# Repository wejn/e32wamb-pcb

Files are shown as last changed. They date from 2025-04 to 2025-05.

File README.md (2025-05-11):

# Hue White Ambiance replacement using ESP32

**Note: This is work in progress, not guaranteed to be usable.**

This will be a pcb for my Hue White Ambiance replacement driver
suitable for my "Beng Ceiling Light" from Philips.

For background info see
[Reversing Philips Hue light driver](https://wejn.org/2024/12/reversing-philips-hue-light-driver/),
or directly the [Final stretch for e32wamb: PCB, cables, antenna
holder](https://wejn.org/2025/05/finishing-stretch-for-e32wamb-pcb-cables-antenna-holder/)
post that discusses the PCB in particular.

## Pretty pictures

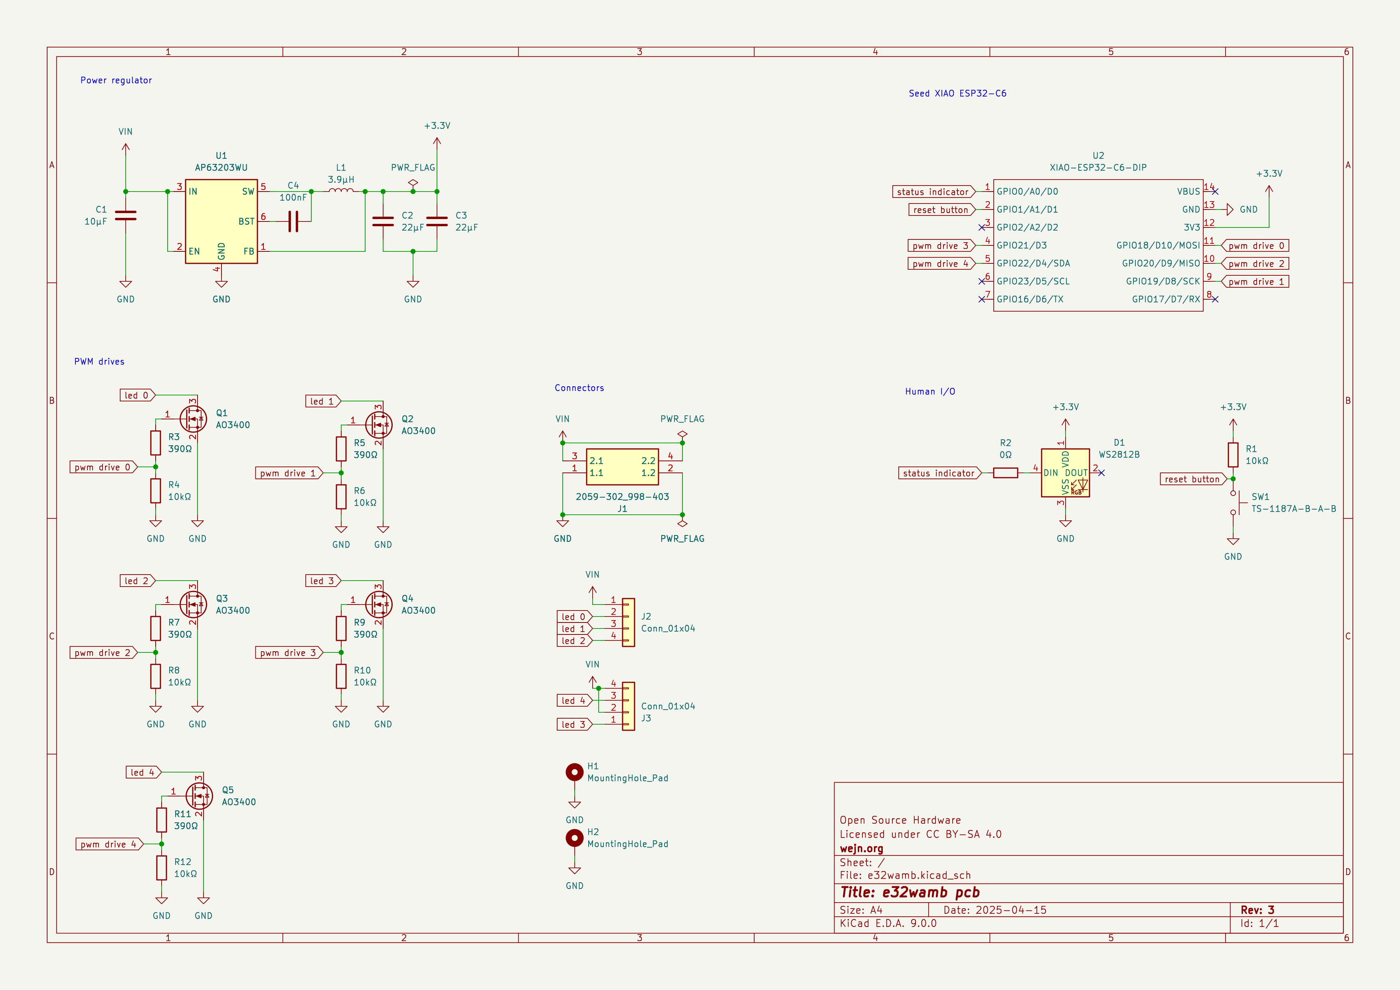
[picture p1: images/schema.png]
schema


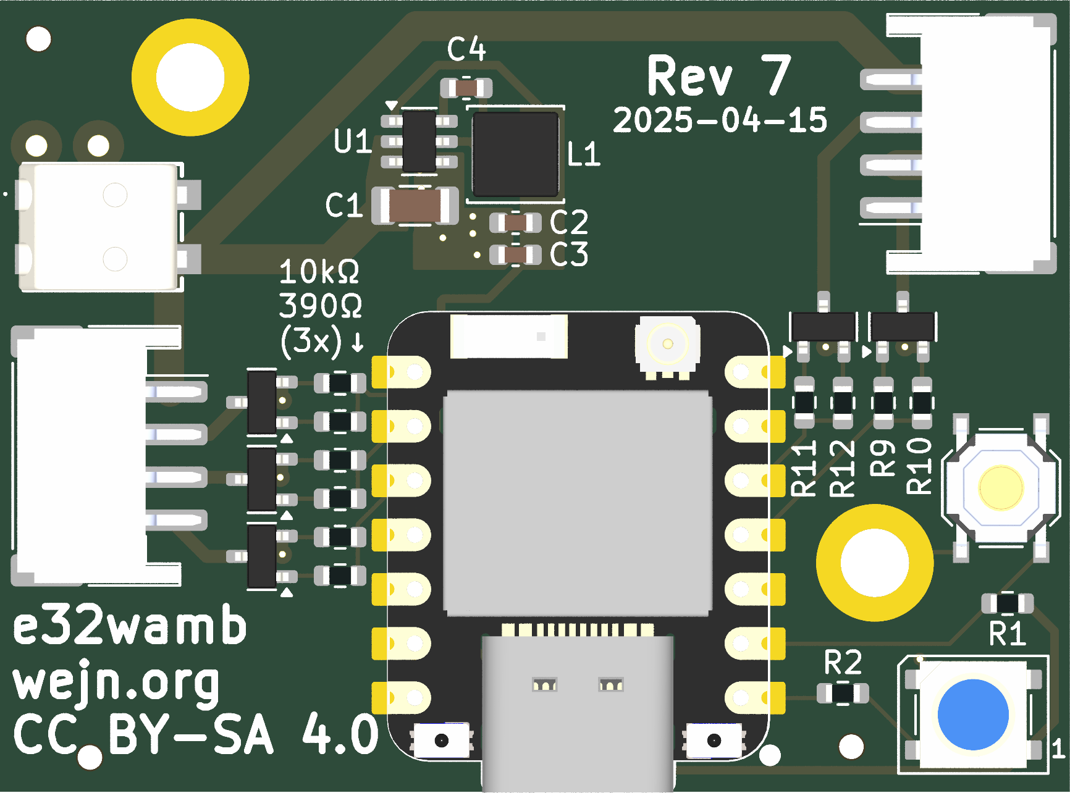
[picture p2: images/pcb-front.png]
pcb front


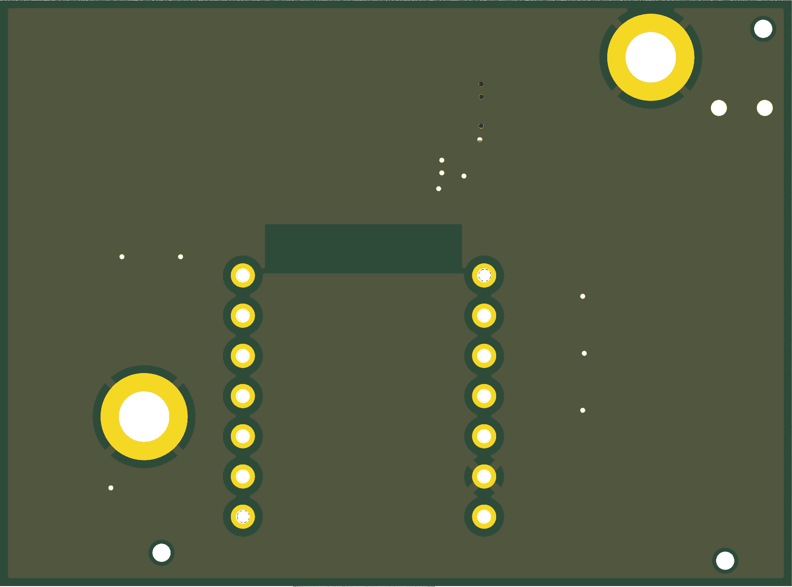
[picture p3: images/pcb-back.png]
pcb back


## License

See the `LICENSE.md` file (tl;dr: CC BY-SA 4.0 for anything by me)

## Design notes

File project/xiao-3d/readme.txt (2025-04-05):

https://grabcad.com/library/seeed-studio-xiao-esp32-c6-1

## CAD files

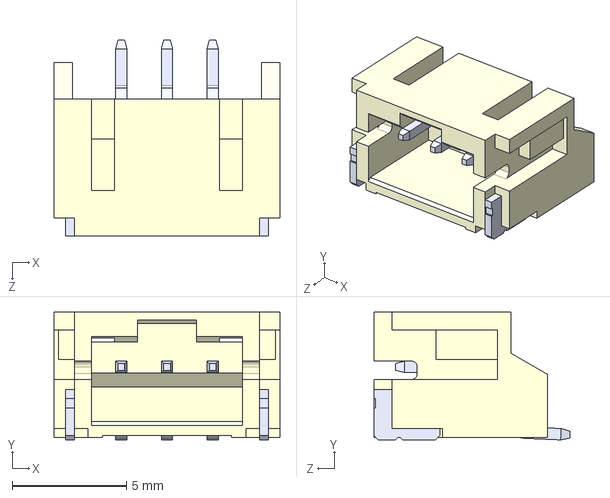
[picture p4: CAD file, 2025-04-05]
project/jst-3d/S3B-PH-SM4-TB--3DModel-STEP-269445.STEP
9.90 x 5.60 x 8.60 mm

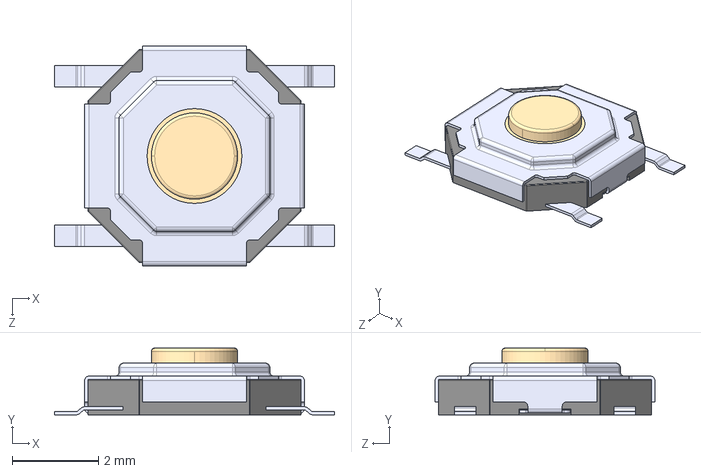
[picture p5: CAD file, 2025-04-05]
project/ts1187a-3d/TS-1187A-B-A-B--3DModel-STEP-56544.STEP
6.50 x 1.55 x 5.10 mm

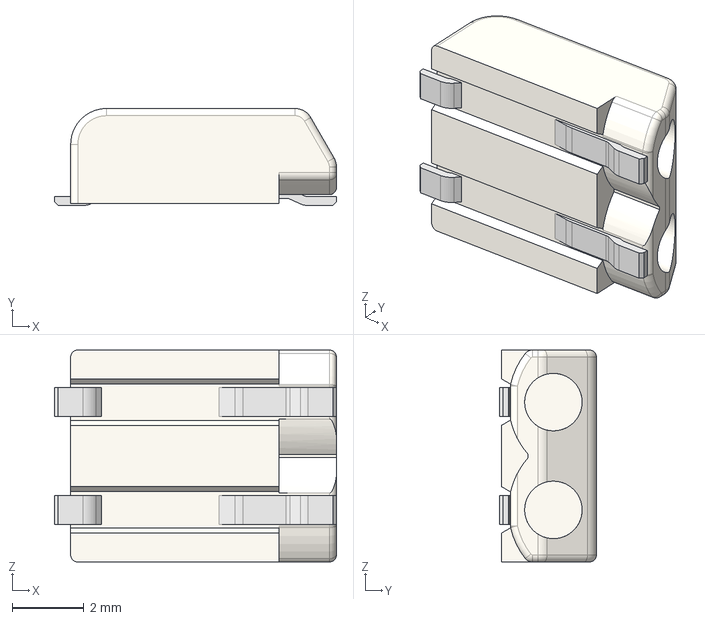
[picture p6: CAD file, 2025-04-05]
project/wago-connector/2059-302_998-403.stp
7.85 x 2.70 x 5.90 mm

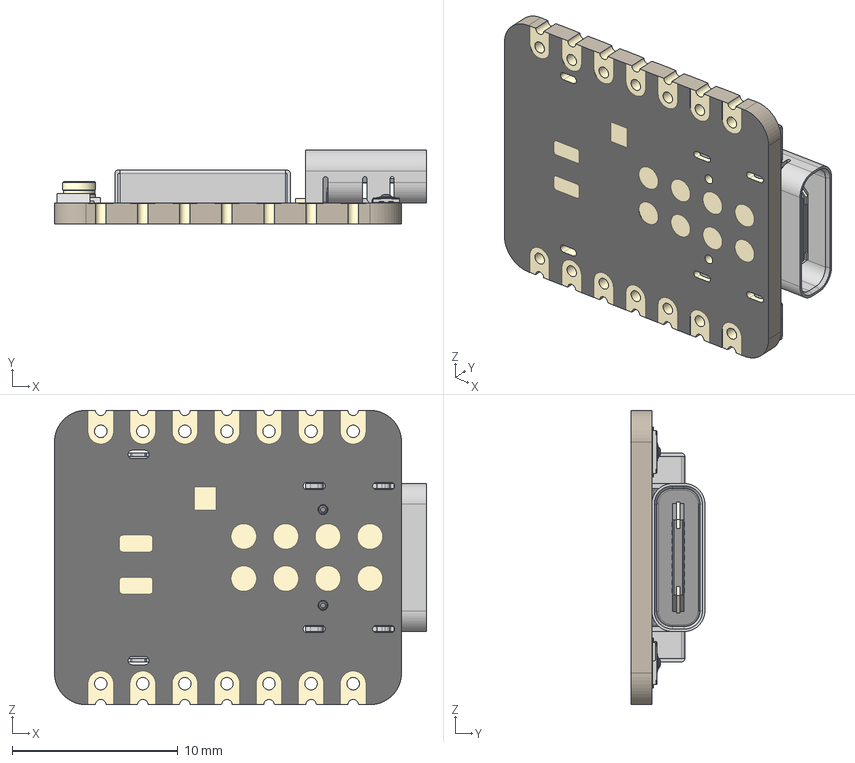
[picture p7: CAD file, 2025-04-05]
project/xiao-3d/Seeed Studio XIAO ESP32-C6.step
22.5 x 4.46 x 17.8 mm
BOSS-EXTRUDE14_8_
BOSS-EXTRUDE7_4_
BOSS-EXTRUDE7_3_
BOSS-EXTRUDE14_4_
BOSS-EXTRUDE14_2_
BOSS-EXTRUDE14_11_
BOSS-EXTRUDE7_7_
BOSS-EXTRUDE14_9_
BOSS-EXTRUDE14_3_
BOSS-EXTRUDE14_7_
MIRROR2
BOSS-EXTRUDE14_5_
BOSS-EXTRUDE14_12_
BOSS-EXTRUDE7_8_
BOSS-EXTRUDE7_1_
BOSS-EXTRUDE14_10_
BOSS-EXTRUDE7_9_
BOSS-EXTRUDE14_6_
BOSS-EXTRUDE14_1_
BOSS-EXTRUDE7_6_
BOSS-EXTRUDE7_2_
CUT-EXTRUDE5
BOSS-EXTRUDE7_5_
U.FL Connector v1
Shield
SKTAAAE010 x 2
KH5220-A36 (Ceramic Antenna) v2

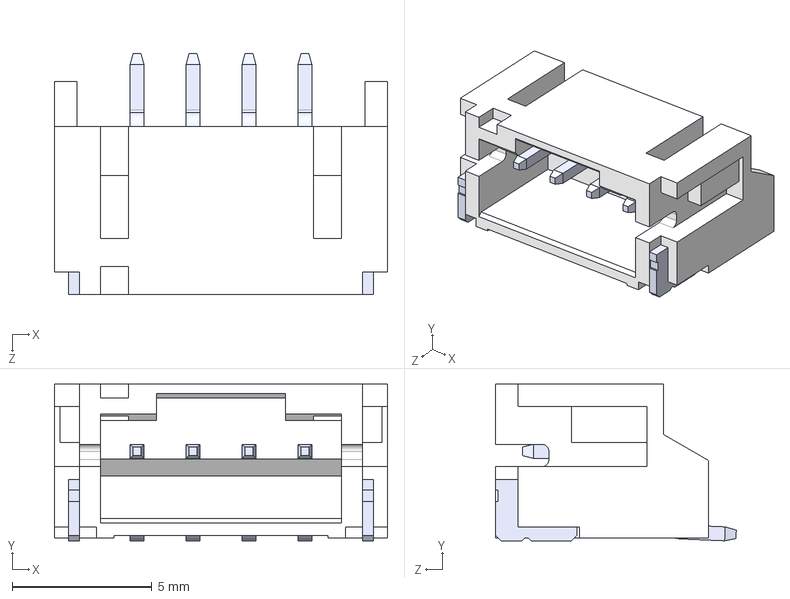
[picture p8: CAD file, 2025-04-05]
project/jst-3d/S4B-PH-SM4-TB--3DModel-STEP-56544.STEP
11.9 x 5.60 x 8.60 mm

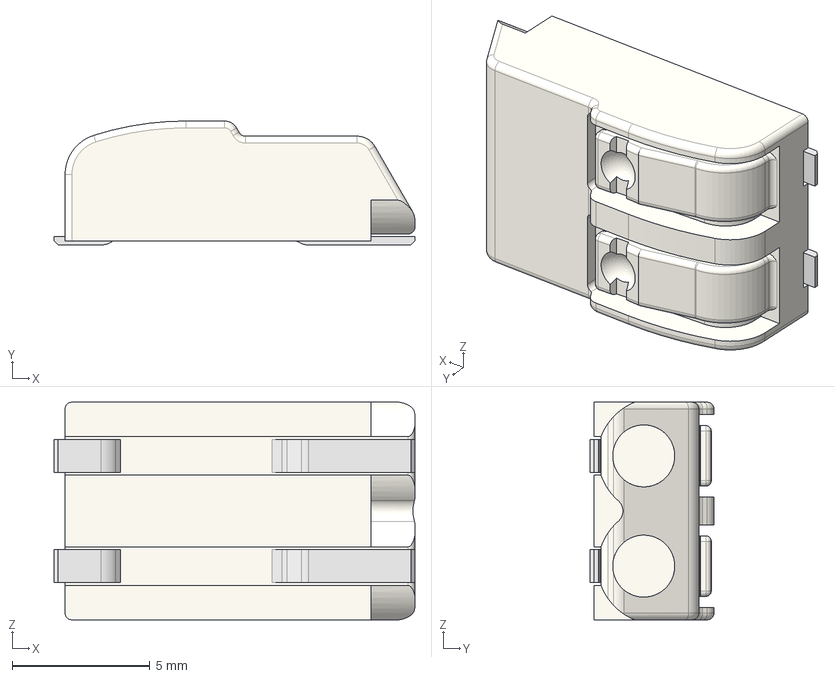
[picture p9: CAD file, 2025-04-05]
project/wago-connector/2060-452_998-404.stp
13.1 x 4.50 x 7.90 mm

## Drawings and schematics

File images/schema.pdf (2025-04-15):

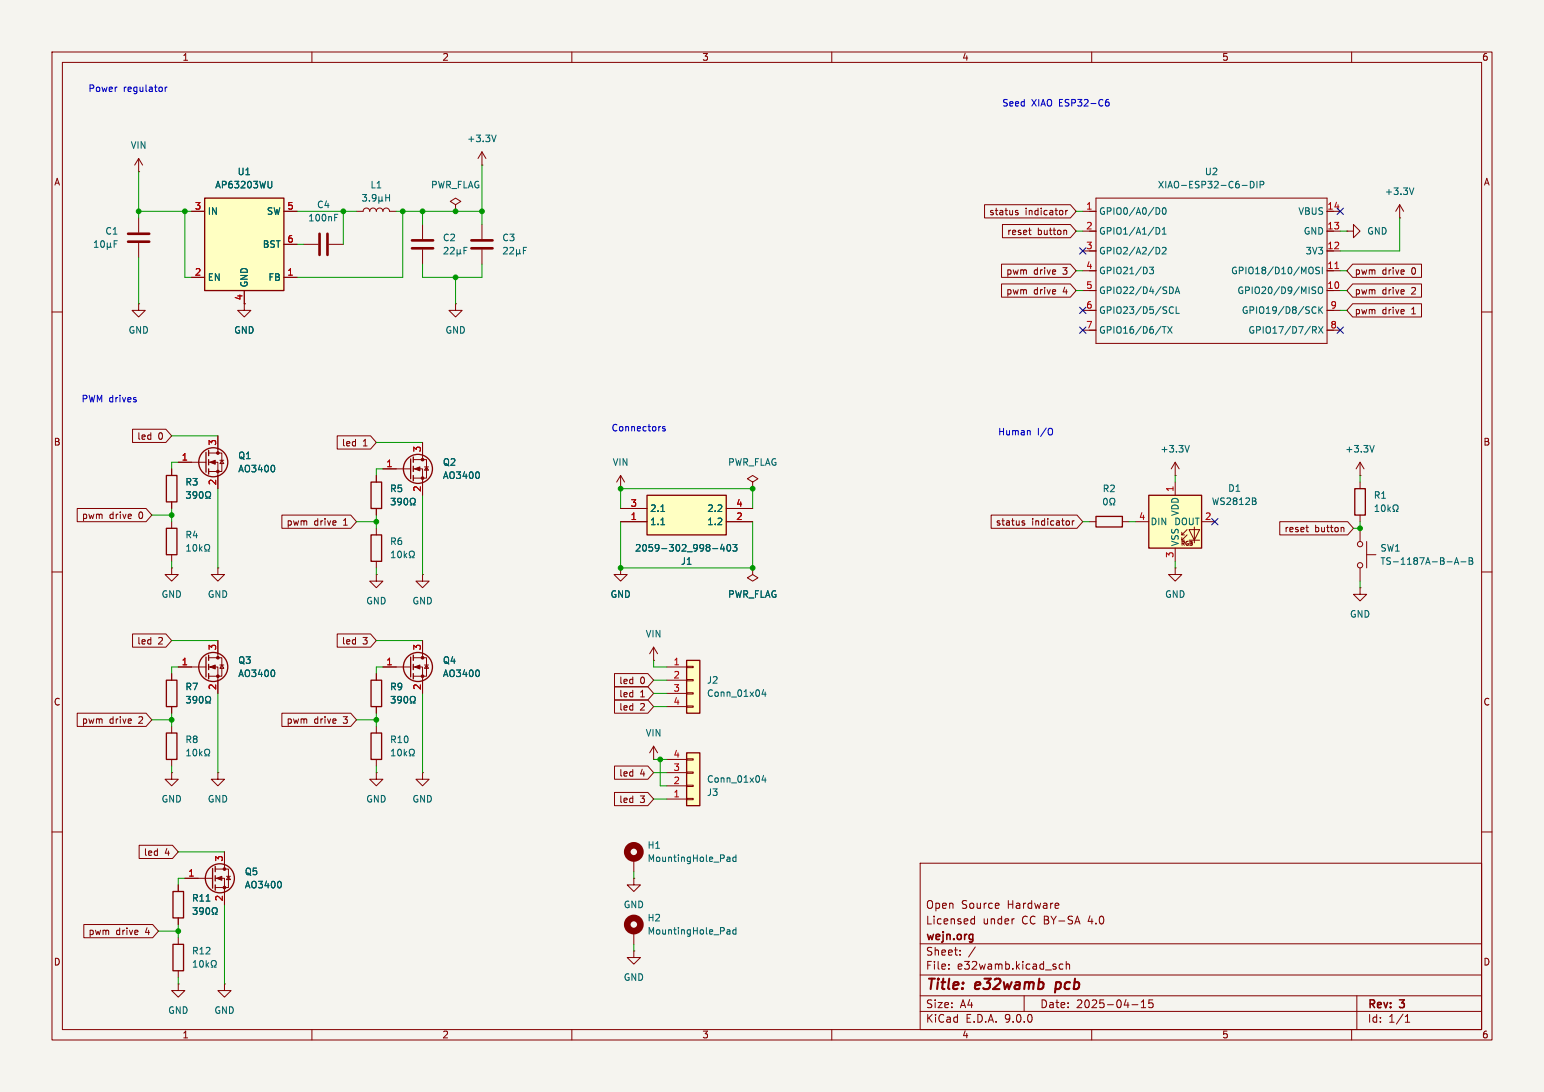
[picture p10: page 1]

4 SW 5 BST 6 FB 1 U1 AP63203WU GND GND

4 SW 5 BST 6 FB 1 GND Q1 AO3400

pwm drive 0
status indicator pwm drive 4

File: e32wamb.kicad_sch Sheet: / wejn.org

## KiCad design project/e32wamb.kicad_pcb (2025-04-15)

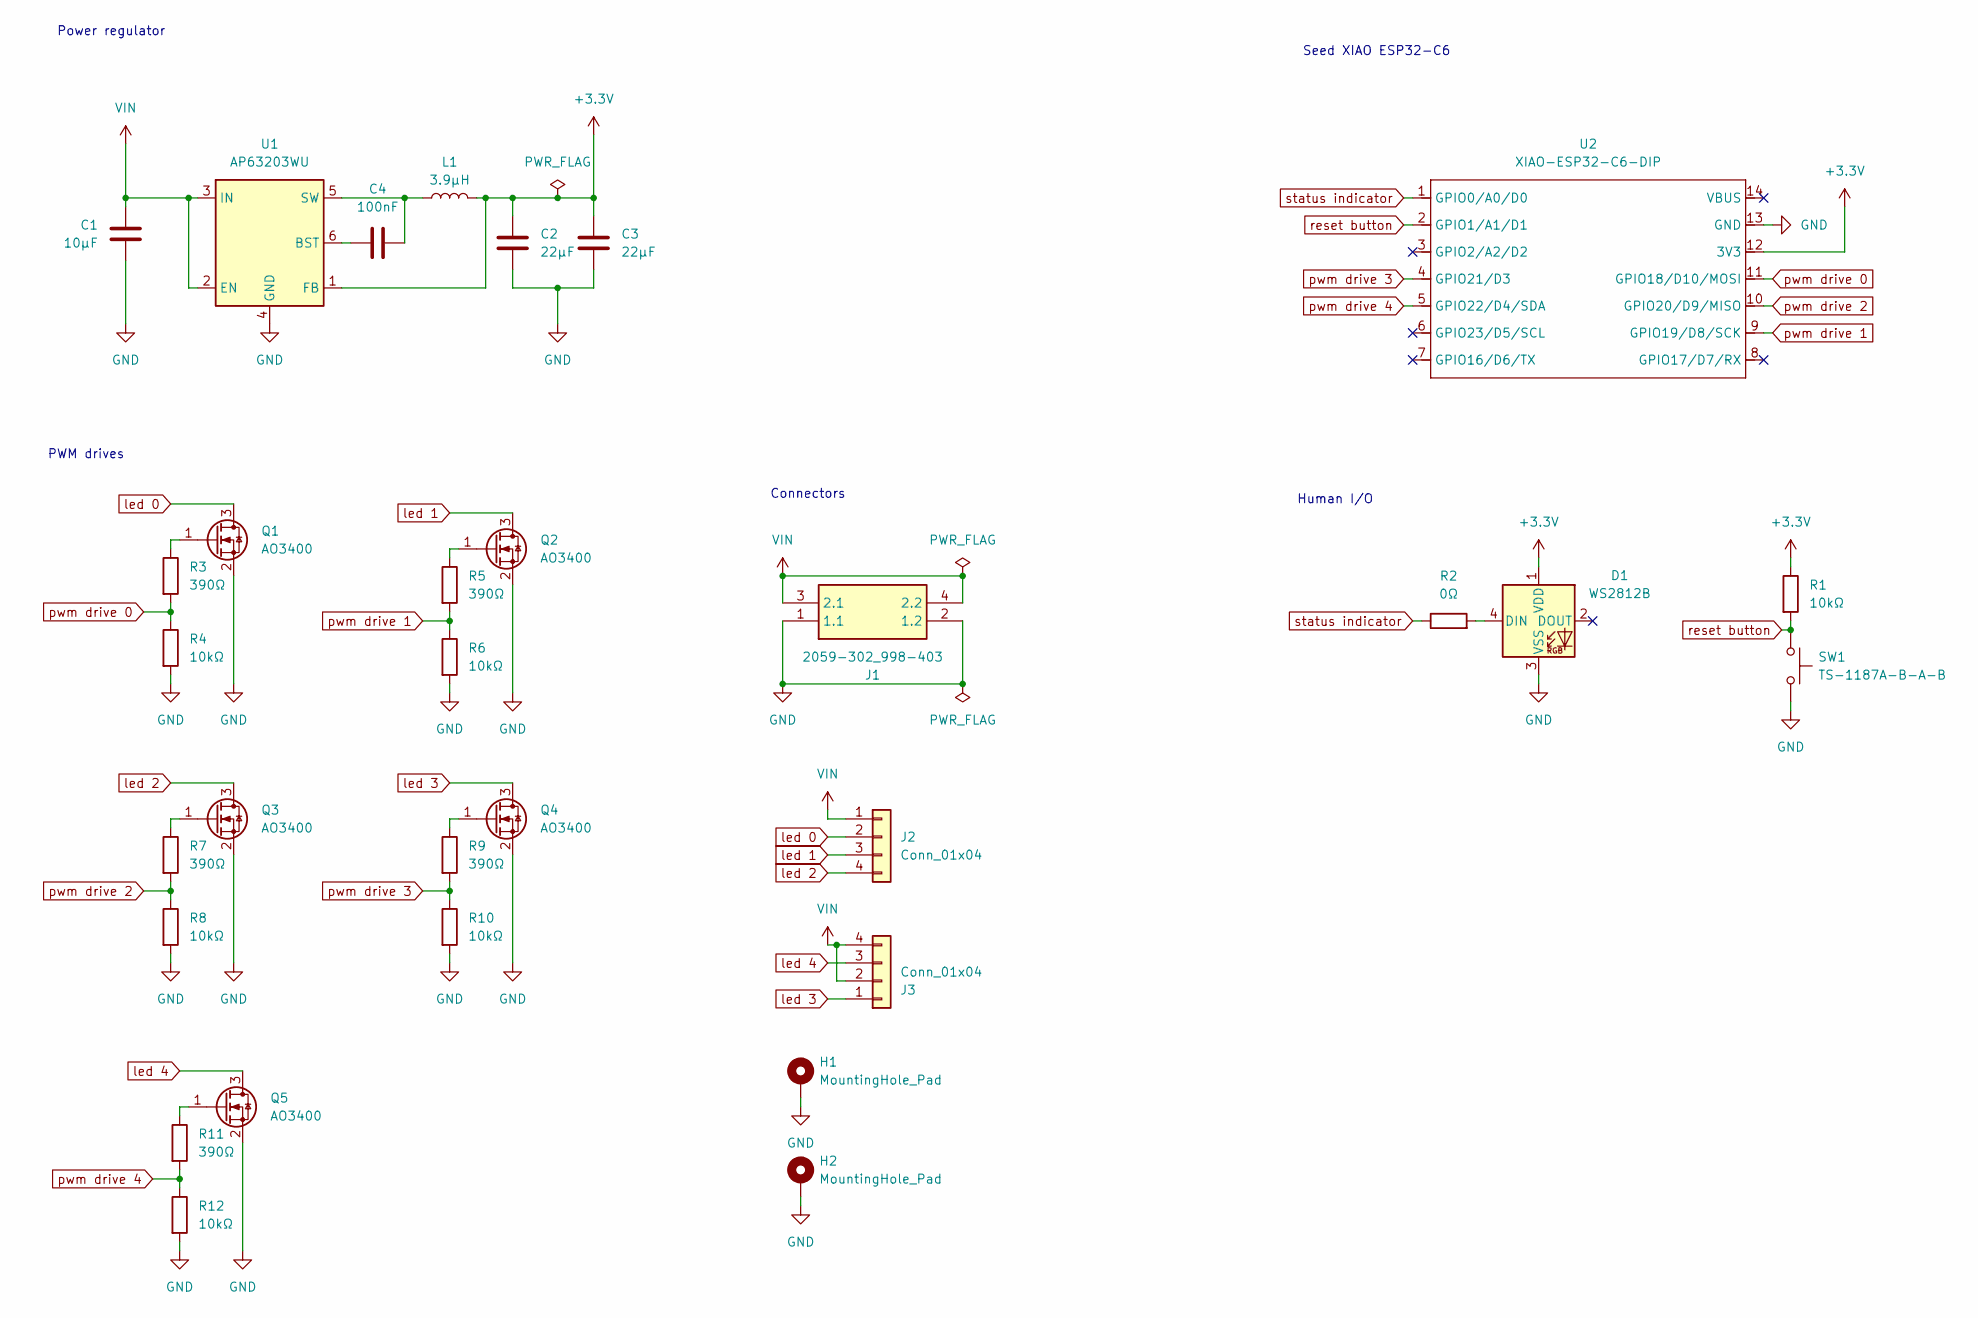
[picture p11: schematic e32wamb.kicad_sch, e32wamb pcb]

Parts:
C1: 10μF; C_1206_3216Metric; LCSC C13585
C2, C3: 22μF; C_0603_1608Metric; LCSC C59461
C4: 100nF; C_0603_1608Metric; LCSC C14663
D1: WS2812B; LED_WS2812B_PLCC4_5.0x5.0mm_P3.2mm; LCSC C2920042
H1, H2: MountingHole_Pad; MountingHole_3.2mm_M3_ISO14580_Pad
J1: 2059-302_998-403; 2059302998403; Manufacturer_Part_Number 2059-302/998-403; LCSC C2765060
J2: Conn_01x04; JST_PH_S4B-PH-SM4-TB_1x04-1MP_P2.00mm_Horizontal; Manufacturer_Part_Number S4B-PH-SM4-TB; LCSC C265102
J3: Conn_01x04; JST_PH_S4B-PH-SM4-TB_1x04-1MP_P2.00mm_Horizontal; Manufacturer_Part_Number S3B-PH-SM4-TB; LCSC C265102
L1: 3.9μH; L_Sunlord_SWPA4030S; PartNo SWPA4030S3R9MT; LCSC C96899
Q1, Q2, Q3, Q4, Q5: AO3400; SOT-23; LCSC C4748804
R1, R4, R6, R8, R10, R12: 10kΩ; R_0603_1608Metric; LCSC C25804
R2: 0Ω; R_0603_1608Metric; LCSC C21189
R3, R5, R7, R9, R11: 390Ω; R_0603_1608Metric; LCSC C23151
SW1: TS-1187A-B-A-B; SW_Push_1P1T_XKB_TS-1187A; LCSC C318884
U1: AP63203WU; TSOT-23-6; LCSC C780769
U2: XIAO-ESP32-C6-DIP; XIAO-ESP32C6-DIP

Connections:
+3.3V: C2.1, C3.1, D1.1 (VDD), L1.2, R1.1, U1.1 (FB), U2.12 (3V3)
GND: C1.2, C2.2, C3.2, D1.3 (VSS), H1.1, H2.1, J1.1 (1.1), J1.2 (1.2), Q1.2 (S), Q2.2 (S), Q3.2 (S), Q4.2 (S), Q5.2 (S), R4.2, R6.2, R8.2, R10.2, R12.2, SW1.2, U1.4 (GND), U2.13 (GND)
unnamed: D1.4 (DIN), R2.2
unnamed: Q1.1 (G), R3.1
unnamed: Q2.1 (G), R5.1
unnamed: Q3.1 (G), R7.1
unnamed: Q4.1 (G), R9.1
unnamed: Q5.1 (G), R11.1
unnamed: C4.2, U1.6 (BST)
unnamed: C4.1, L1.1, U1.5 (SW)
VIN: C1.1, J1.3 (2.1), J1.4 (2.2), J2.1, J3.2, J3.4, U1.2 (EN), U1.3 (IN)
led 0: J2.2, Q1.3 (D)
led 1: J2.3, Q2.3 (D)
led 2: J2.4, Q3.3 (D)
led 3: J3.1, Q4.3 (D)
led 4: J3.3, Q5.3 (D)
pwm drive 0: R3.2, R4.1, U2.11 (GPIO18/D10/MOSI)
pwm drive 1: R5.2, R6.1, U2.9 (GPIO19/D8/SCK)
pwm drive 2: R7.2, R8.1, U2.10 (GPIO20/D9/MISO)
pwm drive 3: R9.2, R10.1, U2.4 (GPIO21/D3)
pwm drive 4: R11.2, R12.1, U2.5 (GPIO22/D4/SDA)
reset button: R1.2, SW1.1, U2.2 (GPIO1/A1/D1)
status indicator: R2.1, U2.1 (GPIO0/A0/D0)

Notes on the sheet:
Human I/O
PWM drives
Connectors
Seed XIAO ESP32-C6
Power regulator

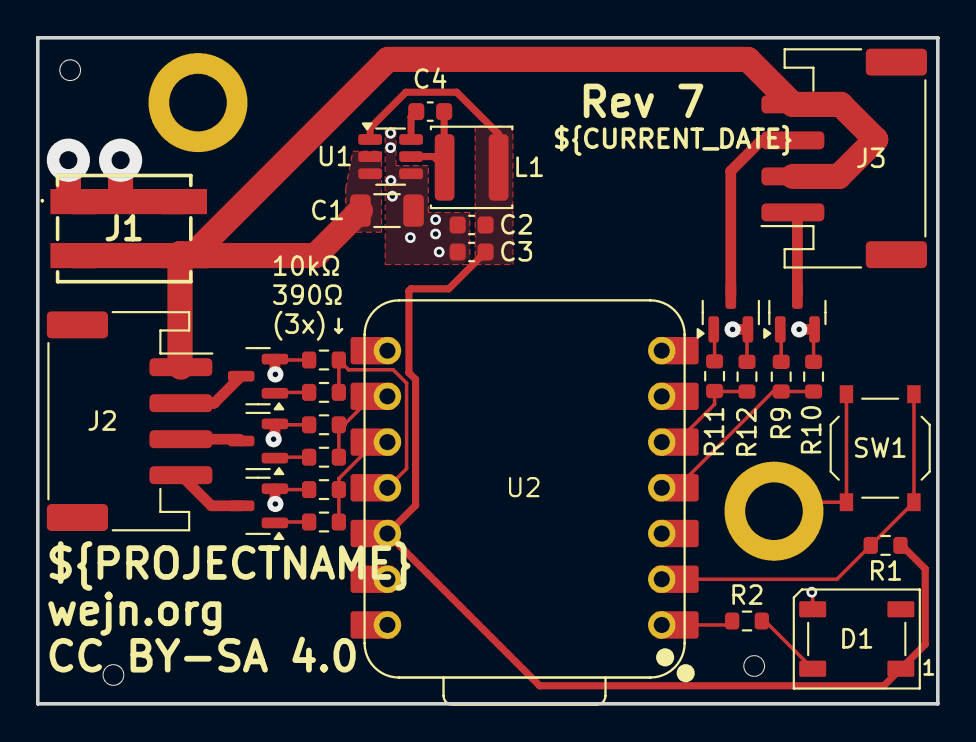
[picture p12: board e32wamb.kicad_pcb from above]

Board: 2 copper layers, 50.0 x 37.0 mm, 31 parts (0 on the bottom side), 23 nets.

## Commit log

2025-04-05 Initial commit: datasheets + schematic
    [e32wamb.kicad_pcb, e32wamb.kicad_sch]
2025-04-05 Update xiao (don't place, add ds+source)
    [e32wamb.kicad_sch]
2025-04-05 Unfuckulate .gitignore, push missing assets
    [2060-452_998-404.stp]
2025-04-05 Add ohm symbol to all Rs, add license info
    [e32wamb.kicad_sch]
2025-04-05 Add 3d models, smaller wago, mounting holes
    [2059-302_998-403.stp, S3B-PH-SM4-TB--3DModel-STEP-269445.STEP, S4B-PH-SM4-TB--3DModel-STEP-56544.STEP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]
2025-04-06 Flip connector, fix mosfet type and footprint
    [e32wamb.kicad_sch]
2025-04-06 First shot at the pcb (layout only, no wiring yet)
    [e32wamb.kicad_pcb]
2025-04-08 First shot at wiring (complete pcb)
    [e32wamb.kicad_pcb]
2025-04-08 Fix mounting hole h2 footprint
    [e32wamb.kicad_pcb, e32wamb.kicad_sch]
2025-04-09 Add lcsc part number for smaller wago
    [e32wamb.kicad_sch]
2025-04-09 Oops: c2,c3 were wrong footprint (lcsc num)
    [e32wamb.kicad_sch]
2025-04-09 Add jlcpcb tooling holes
    [e32wamb.kicad_pcb]
2025-04-09 Oops: c2,c3 were wrong lcsc num, even on pcb
    [e32wamb.kicad_pcb]
2025-04-09 Purge fp-info-cache and *.kicad_prl
2025-04-09 Add rotation offset for U1 (for jlcfab), bump revision
    [e32wamb.kicad_pcb, e32wamb.kicad_sch]
2025-04-09 Add pics, Makefile, jlc-fab-toolkit
    [transformations.csv]
2025-04-10 Tune spacing between mounting holes; switch to vars for revision + date
    [e32wamb.kicad_pcb, e32wamb.kicad_sch]
2025-04-11 Add keepout zone around the antenna
    I thought I could do without because I'll be using an external antenna,
    but it hardly costs anything. So why not have the keepout just in case.
    [e32wamb.kicad_pcb]
2025-04-13 More space around J3, thicker VIN for buck
    Based on Sam's review.
    [e32wamb.kicad_pcb]
2025-04-13 Switch the esp32-c6 to DIP footprint
    Sam suggested it might make the debugging a bit easier.
    [e32wamb.kicad_pcb, e32wamb.kicad_sch]
2025-04-13 Slightly increase the keepout around antenna
    [e32wamb.kicad_pcb]
2025-04-13 Switch J3 to 4-pin JST PH
    Not only will that give me two additional independent chans, but
    also one less BOM part to deal with (cheaper for PCBA).
    [e32wamb.kicad_pcb, e32wamb.kicad_sch]
2025-04-15 Fix wrong J3 LCSC part number
    Forgot to fix this in 7358522f.
    [e32wamb.kicad_pcb, e32wamb.kicad_sch]

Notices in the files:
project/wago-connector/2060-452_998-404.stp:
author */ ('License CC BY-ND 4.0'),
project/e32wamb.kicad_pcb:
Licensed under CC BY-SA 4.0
